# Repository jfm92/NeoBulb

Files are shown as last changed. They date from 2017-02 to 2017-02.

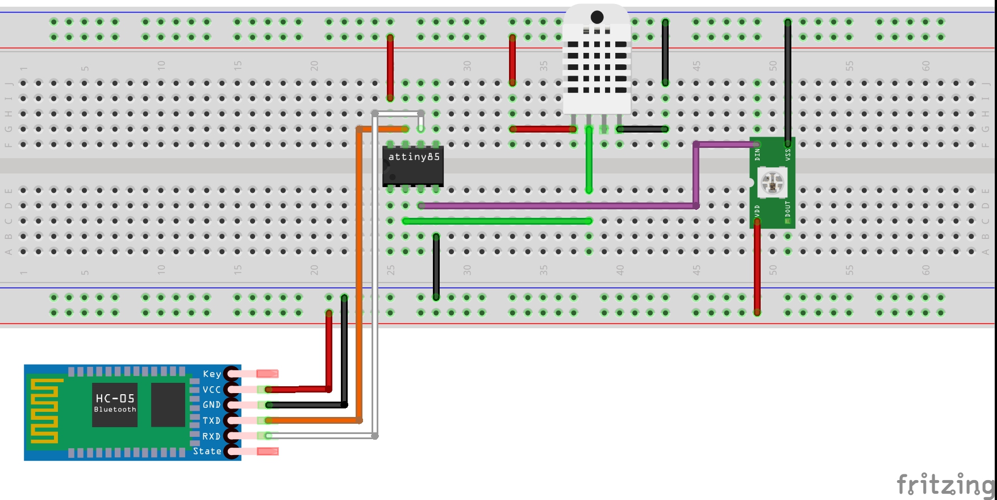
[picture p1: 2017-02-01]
esquema_protoboard.jpg

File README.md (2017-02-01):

#NeoBulb

Detailed instructions:
http://www.instructables.com/id/NeoBulb-Neopixel-Bulb-With-Sensor/

This project was done for 'Creative Electronics', a Beng Electronics Engineering 4th year module at the University of Málaga, School of Telecommunications. (www.etsit.uma.es).

This project is a bulb with Bluetooth communication that can change colour brightness and create special effects with lights powered by 2 Neopixel Rings, it also has the possibility to connect a external sensor to measure outside parameters like temperature, humidity, move...

And a special fact, that is quite important nowadays, is that it onlyconsumes around 4W a maximum in white and with maximum luminosity.

Every parameter is controlled by an Android APP, that shows:

The mesure of the humidity and the temperature of the room in which the bulb is
Change the colour of the bulb.
To Program the default colour of the bulb that is an option if you want to use like a regular bulb.
Special lights effects , like an Aurora, light of a candle or random colors every 5 sec.
All the circuits are embedded in a regular bulb of 15W of which I only used the body.

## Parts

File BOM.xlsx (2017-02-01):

Name | Quantity | Price(€) | Link
AtTiny85 | 1 | 3.75 € | Farnell (http://es.farnell.com/atmel/attiny85-20pu/mcu-8bit-attiny-20mhz-dip-8/dp/1455162?mckv=T3AHUOcX_dc|pcrid|47060866989|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)
15W Led Bulb | 1 | 4.5 €
Neopixel 8bit Ring | 1 | 3.18 | Banggood (http://www.banggood.com/CJMCU-8-Bit-WS2812-5050-RGB-LED-Driver-Development-Board-p-976037.html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)
Neopixel 12bit Ring | 1 | 3.4 | Banggood (http://www.banggood.com/CJMCU-12-Bit-WS2812-5050-RGB-LED-Driver-Development-Board-p-984259.html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)
Bluetooth module HC06 | 1 | 4.62 | Banggood (http://www.banggood.com/HC-06-Wireless-Bluetooth-Transceiver-RF-Main-Module-Serial-For-Arduino-p-80364.html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)
PCB 46mmx46mm | 1 | 1 | Estimated Price
LG nexus 4 Phone Charger | 1 |  | Unknow Price
Humitidty/Temperature Sensor DHT11 | 1 | 1.70 € | Bangood (http://www.banggood.com/Wholesale-DHT11-Digital-Temperature-Humidity-Sensor-Moudle-Probe-For-HVAC-Arduino-4pin-p-47424.html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)
 |  | 22.15 €

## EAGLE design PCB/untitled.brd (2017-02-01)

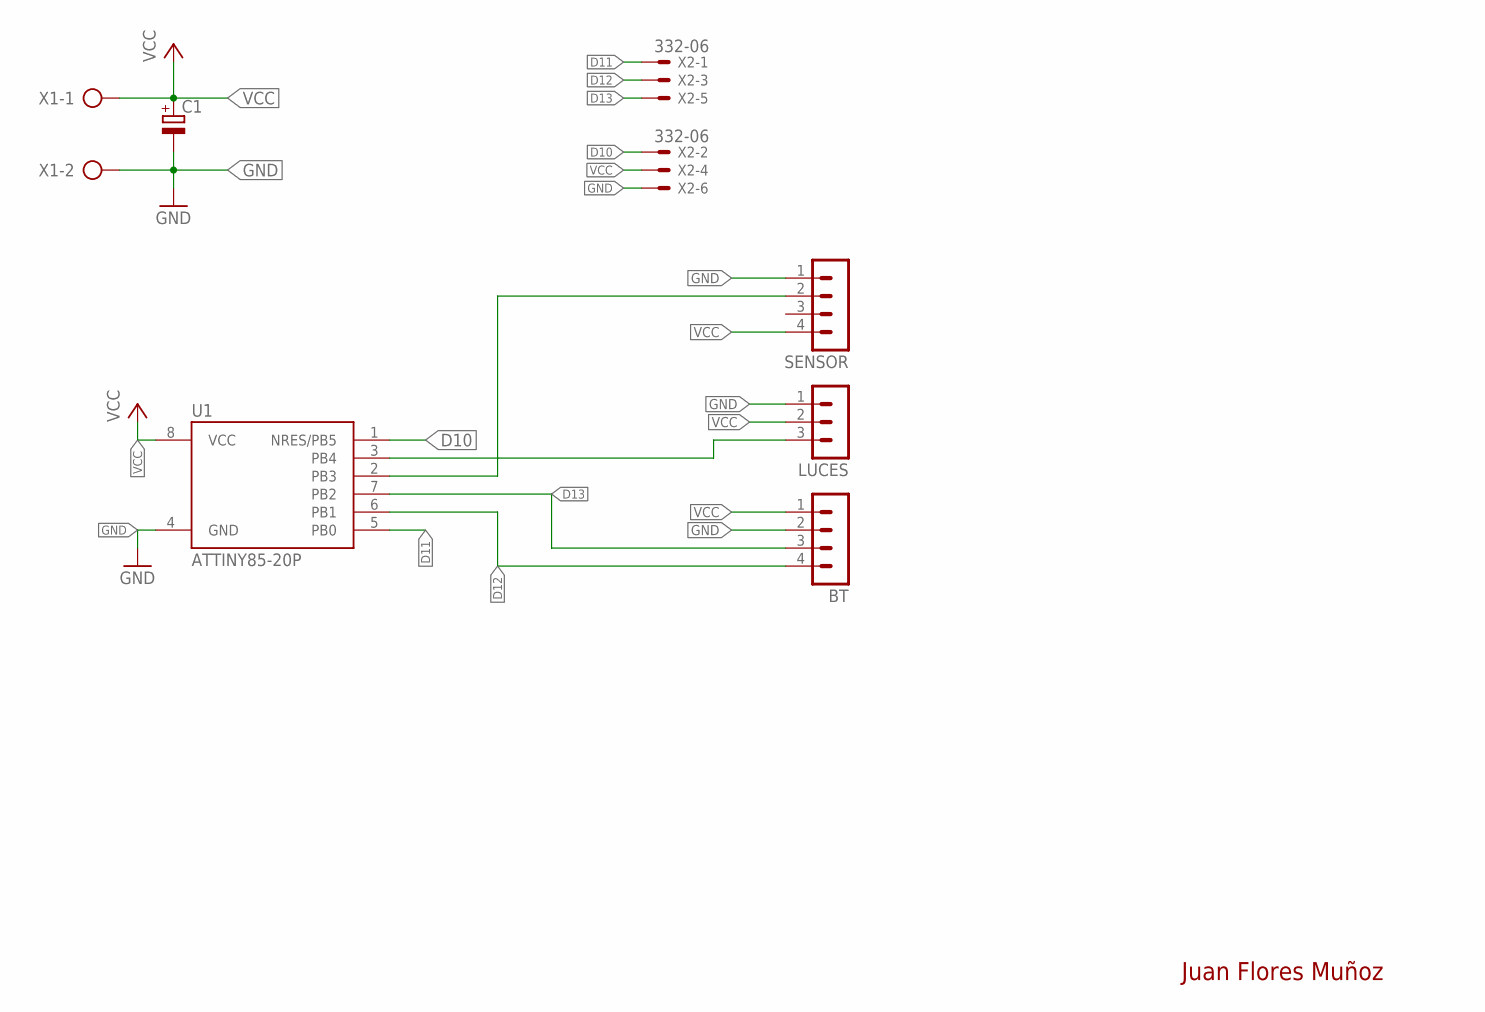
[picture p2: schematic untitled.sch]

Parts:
BT: MA04-1
C1: CPOL-EUE2,5-6E; E2,5-6E
LUCES: MA03-1
SENSOR: MA04-1
U1: ATTINY85-20P; PDIP08_300MIL
X1: AK500/2
X2: 332-06

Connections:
01: SENSOR.2, U1.2 (PB3)
D10: U1.1 (NRES/PB5), X2.2
D11: U1.5 (PB0), X2.1
D12: BT.4, U1.6 (PB1), X2.3
D13: BT.3, U1.7 (PB2), X2.5
GND: BT.2, C1.-, LUCES.1, SENSOR.1, U1.4 (GND), X1.2, X2.6
unnamed: LUCES.3, U1.3 (PB4)
VCC: BT.1, C1.+, LUCES.2, SENSOR.4, U1.8 (VCC), X1.1, X2.4

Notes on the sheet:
Juan Flores Muñoz

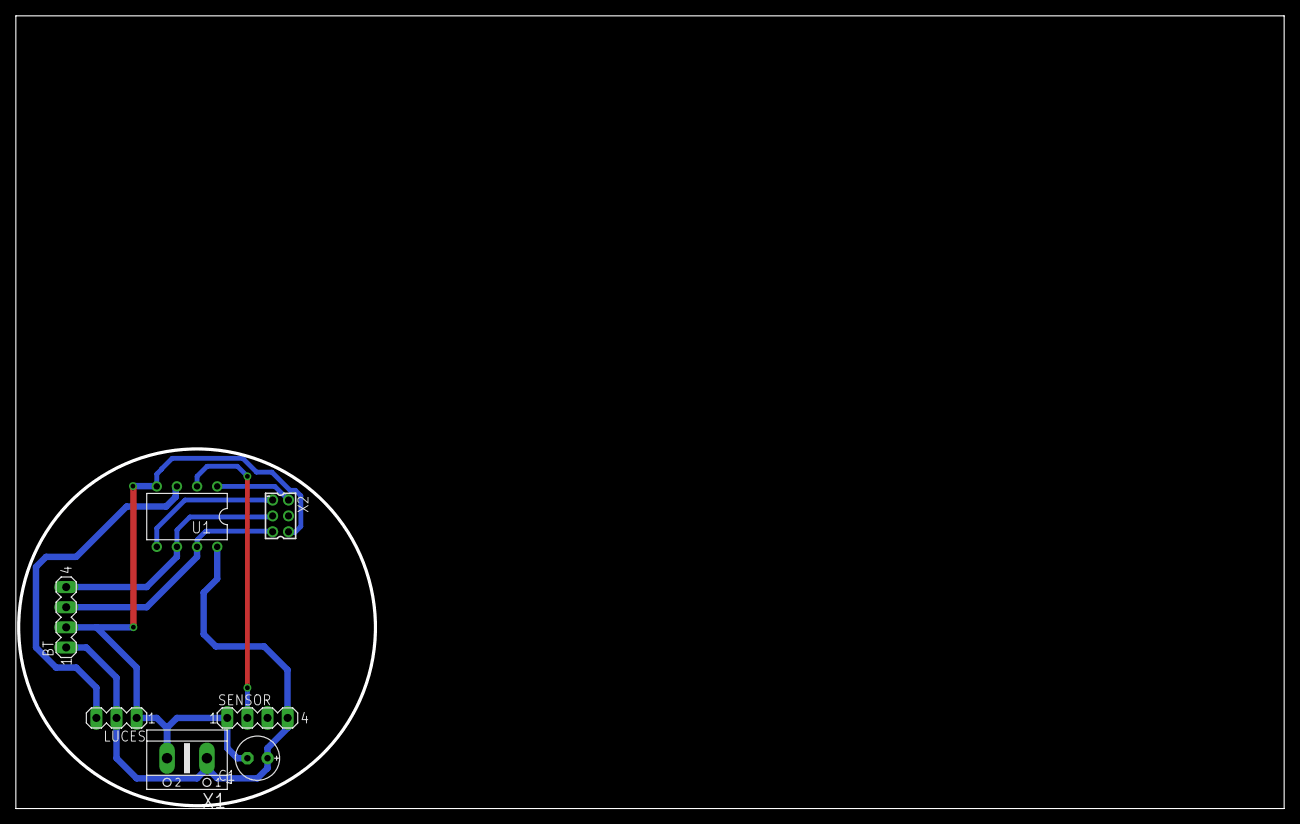
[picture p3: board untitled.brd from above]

Board: 2 copper layers, 160.0 x 100.0 mm, 7 parts (0 on the bottom side), 8 nets.

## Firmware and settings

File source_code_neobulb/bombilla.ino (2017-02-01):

/*******************************************
 * Proyecto realizado por Juan Flores Muñoz
 * Electronica Creativa
 * 4º GISE
 *******************************************/


#include <Adafruit_NeoPixel.h>
#include <SimpleDHT.h>
#include <EEPROM.h>
#include <SoftwareSerial.h>

//Configuration Neopixel
#ifdef __AVR__
  #include <avr/power.h>
#endif

#define PIN 4           
#define NUMPIXELS      21
Adafruit_NeoPixel pixels = Adafruit_NeoPixel(NUMPIXELS, PIN, NEO_GRB + NEO_KHZ800);

//Configuration DHT11(Temp and humidity sensor)
int pinDHT11 = 5;
SimpleDHT11 dht11;

SoftwareSerial PSerial(1, 2);

//configuration EEPROM
int dir=0;
//it's neccesary to divide dir, because you can only write in eeprom byte once time
byte b_red;//1byte can load 0 to 255
byte b_green;//1byte can load 0 to 255
byte b_blue;//1byte can load 0 to 255

byte inicio;//to know if it's first time that it's load

void setup() {
  
  PSerial.begin(9600);
  pixels.begin();
  init_conf();//set the preconfigure value to initalitation
}

void loop() {
  rCommand();//read input from serial port and analyze wich command is receiving
}

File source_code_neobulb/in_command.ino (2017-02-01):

/*******************************************
 * Proyecto realizado por Juan Flores Muñoz
 * Electronica Creativa
 * 4º GISE
 *******************************************/


//Read serial commands and decide wich command is and which values have
String buff_in;//buffer to load input datas

char r_aux[4],g_aux[4],b_aux[4];
int r,g,b;//final data to introduce
int i,e;

bool error=0;
void rCommand(){
  
  if(PSerial.available()>0){//Waiting for input
    buff_in=PSerial.readString();//command receive
    switch(buff_in[0]){
      case 't'://asking about temperature
          get_temp();
      break;

      case 'c'://to configure a static colour
        
        /**********Red Value******************/
        i=0;
        while(1){//looking for red value
          if(buff_in[i+1]=='/'){
            if(i==2){//if the value that we receive have 2 digits or 1 en caso que solo tenga 2 digitos
              r_aux[2]=r_aux[1];
              r_aux[1]=r_aux[0];
              r_aux[0]='0';
            }
            else if(i==1){//si tiene solo 1 digito
              r_aux[2]=r_aux[0];
              r_aux[1]='0';
              r_aux[0]='0';
            }
             break;
          }
          else{
            r_aux[i]=buff_in[i+1];//introducing into char array for red value
          }
          i++;
          if(i==4){
            error = 1;
            break;
          }
        }

        if(error != 1){
           r_aux[3]='\0';
           r=atoi(r_aux);//transforming to int value
        }
        else{
          error=0;
        }
      
        
        /**************Green Value**************/
         e=i+2;
         i=0;
         while(1){//looking for red value
          if(buff_in[e]=='/'){
            if(i==2){//if the value that we receive have 2 digits or 1
              g_aux[2]=g_aux[1];
              g_aux[1]=g_aux[0];
              g_aux[0]='0';
            }
            else if(i==1){
              g_aux[2]=g_aux[0];
              g_aux[1]='0';
              g_aux[0]='0';
            }
             break;
          }
          else{
            g_aux[i]=buff_in[e];//introducing into char array for red value
          }
          e++;
          i++;
          if(i==4){
           error=1;
           break;
         }
          
        }
        
       if(error != 1){
           g_aux[3]='\0';
           g=atoi(g_aux);//transforming to int value
      }
      else{
        error=0;
      }
      
       /************Blue Value*******************/
        i=e+1;
        e=0;
         while(1){//looking for red value
          if(buff_in[i]=='/'){
            if(e==2){//if the value that we receive have 2 digits or 1
              b_aux[2]=b_aux[1];
              b_aux[1]=b_aux[0];
              b_aux[0]='0';
            }
            else if(e==1){
              b_aux[2]=b_aux[0];
              b_aux[1]='0';
              b_aux[0]='0';
            }
             break;
          }
          else{
            b_aux[e]=buff_in[i];//introducing into char array for red value
          }
          e++;
          i++;
          if(e==4){//more characters than should be
            error=1;
            break;
          }
        }
       if(error != 1){
           b_aux[3]='\0';
           b=atoi(b_aux);//transforming to int value
        }
        else{
          error=0;
        }
       //falta implementar el brillo
        set_color(r,g,b);
      break;

      case 'e'://to start special mode
        char c_aux[2];
        c_aux[0]=buff_in[1];
        c_aux[1]='\0';
        int aux;
        aux=atoi(c_aux);
        extra(aux);//choose special mode
      break;
      
      case 's':
        //save default color value in EEPROM
        b_red=r;
        b_green=g;
        b_blue=b;
        inicio=1;
        
        EEPROM.write(dir, b_red);
        EEPROM.write(dir+1, b_green);
        EEPROM.write(dir+2, b_blue);
        EEPROM.write(dir+3, inicio);
        
      break;

      default:
        
      break;

    
    }
    
  }
}
